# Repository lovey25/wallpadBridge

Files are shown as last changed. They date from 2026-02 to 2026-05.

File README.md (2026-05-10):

# 아파트 월패드 RS485-MQTT 브릿지 모듈

## 1. 프로젝트 개요

아파트 내부 RS485 네트워크(월패드-각 가전기기 간 통신)에 접속하여 데이터를 모니터링하고 제어 명령을 전달하는 하이브리드 IoT 게이트웨이 구축.

## 2. 시스템 아키텍처

지원 보드: **Wemos D1 Mini (ESP8266)**, **ESP-12E (ESP8266)**, **ESP32**

Physical Layer: 월패드 RS485 라인 (9600bps, 12V 전원부 활용)
Transport Layer: WiFi (802.11 b/g/n)
Application Layer: MQTT (v3.1.1), WebSocket (실시간 로그), HTTP (설정 및 제어)

## 3. 기능 상세 정의 (Functional Requirements)

### 3.1 네트워크 및 설정 관리

- **WiFi 자동 프로비저닝**: 저장된 WiFi 정보가 없거나 접속 실패 시 자동으로 AP 모드(Wallpad_Setup) 진입
- **웹 기반 설정 UI**:
  - `/wifi.htm`: WiFi 네트워크 스캔 및 연결 설정
  - `/config.htm`: WiFi + MQTT 통합 설정 관리
  - 실시간 WiFi 스캔 (WebSocket 기반, 비동기)
  - 설정 저장 후 자동 재부팅
- **REST API**:
  - `GET/POST /api/config`: WiFi/MQTT 설정 조회 및 업데이트
  - `GET /api/devices`: 모든 장치 상태 조회
- **영구 저장**: LittleFS 파일시스템 (256KB, config.json)

### 3.2 RS485 통신 및 디버깅 (보드별 시리얼 방식)

- **양방향 프로토콜 브릿지**:
  - RS485 → MQTT: 수신 패킷을 파싱하여 MQTT Topic으로 발행
  - MQTT → RS485: MQTT 명령을 RS485 프레임으로 변환 송신
  - 지원 장치: 조명(Light), 환기팬(Fan), 도어락(DoorLock), 온도조절기(Climate)
- **TX 큐 시스템**:
  - 6슬롯 원형 큐로 RS485 송신 직렬화 (WS / MQTT / HTTP / Poll 소스 구분)
  - 버스 Idle 대기(20ms) + TX 최소 간격(50ms) + 강제 송신 타임아웃(500ms)
  - 큐 오버플로 시 MQTT 경고, TX 통계 60초마다 `home/wallpad/diag/tx` 발행
- **3분 주기 상태 폴링**: 조명 3 + 온도조절기 4 = 7패킷 순차 발행 (PROGMEM 저장)
- **실시간 모니터링**:
  - `/monitor.htm`: WebSocket 기반 실시간 시리얼 로그 뷰어
  - `/ws`: 양방향 WebSocket 엔드포인트 (RS485 ↔ Web)
  - HEX 포맷 패킷 표시 및 장치 타입/명령 디코딩
  - `/api/rs485/send`: HEX 문자열 직접 송신 (F7…EE 프레임 검증 후 큐 추가)
  - `/api/rs485/diag`: TX 큐 통계 실시간 조회
- **Binary 센서**: 3채널 접점 신호 감지 (Pull-up, 12V 입력)
  - D1 Mini / ESP-12E: D5 / D6 / D7 (GPIO14 / GPIO12 / GPIO13)
  - ESP32: GPIO25 / GPIO26 / GPIO27

### 3.3 Home Assistant 연동

- **MQTT Discovery**: 재부팅 시 자동으로 장치 등록 메시지 발행
  - Light 엔티티 3개 (거실1 거실2, 3way)
  - Fan 엔티티 (속도 제어 1-3단)
  - Door Lock 엔티티 (도어락 제어 응답 기반, SubCommand `0x43`)
  - Climate 엔티티 4개 (온도조절기 4개(거실, 안방, 작은방1, 작은방2), 모드/온도 제어)
  - Binary Sensor 엔티티: 외부 접점 3개 + RS485 현관문 1개 (`device_class: door`, broadcast SubCommand `0x40`)
  - Device 정보(`bridge_info.h`): 식별자/이름/모델/제조사/버전 단일 헤더로 분리 — `credentials.h` 또는 PlatformIO `build_flags`로 override 가능
- **가용성 관리**: LWT(Last Will and Testament)를 통한 온라인/오프라인 상태 실시간 모니터링
- **상태 동기화**: RS485 장치 상태 변경 시 즉시 MQTT 발행 (변경 감지 기반)

### 3.4 시스템 안정성

- **Watchdog 타이머**: WiFi/MQTT 연결 상태 감시 (30초 주기)
- **RS485 활동 Watchdog**: 부팅 5분 후 활성화, 10분 무수신 시 MQTT 경고 후 자동 재부팅
- **연속 invalid frame 감지**: 100회 연속 or 512바이트 내 정상 프레임 없으면 파서 강제 리셋
- **메모리 모니터링**: 10초마다 힙 메모리 체크, 10KB 이하 시 경고
- **자동 재연결**: WiFi 연결 끊김 시 자동 재시도 (3회 실패 시 재부팅)
- **안전한 재부팅**: HTTP 응답 완료 후 지연 재부팅 (Exception 방지)
- **WDT 리셋 방지**: 비동기 WiFi 스캔, Ticker ISR 안전성 확보

### 3.5 OTA 펌웨어 업데이트

- **ArduinoOTA 지원**: WiFi STA 연결 시 OTA 서비스 자동 활성화
- **호스트명 설정**: `OTA_HOSTNAME` 매크로로 네트워크 식별 이름 지정
- **비밀번호 보호**: `OTA_PASSWORD` 매크로로 OTA 인증 설정 가능
- **업데이트 상태 반영**: OTA 진행 중 MQTT 상태를 `updating`으로 발행

### 3.6 성능 최적화

- **WiFi 스캔 최적화**:
  - Hidden SSID 스캔 제외로 스캔 시간 10배 단축
  - 비동기 스캔으로 UI blocking 제거
  - scanDelete()로 메모리 효율성 개선
- **WebSocket 즉시 연결**:
  - monitor.htm의 script를 body 끝으로 이동하여 HTML 파싱 blocking 제거
  - CSS 외부 파일화로 페이지 크기 26% 감소
  - 페이지 전환 시 WebSocket 정리 로직 개선 (다중 이벤트 리스너)
  - 연결 시간: 8초 → 20ms (400배 개선)
- **백엔드 비동기 처리**:
  - MQTT 연결을 부팅 20초 후로 지연 (웹 서버 우선 응답)
  - Discovery를 200ms 간격으로 분산 발행 (blocking 최소화)
  - MQTT 버퍼 크기 1024바이트로 확대 (Climate discovery 메시지 지원)
- **파일 시스템 접근 최적화**:
  - 정적 파일 서빙 시 fileSystemBusy 체크 제거 (읽기 전용은 안전)
  - 동시 요청 처리 개선

### 3.7 RS485 통신 규격

프로토콜 상세 명세는 [wallpad_protocol.md](./wallpad_protocol.md) 참조

## 4. 하드웨어 설계 (Hardware Specifications)

### 4.1 주요 부품 리스트

- MCU: **Wemos D1 Mini** 또는 **ESP-12E** (ESP8266) 또는 **ESP32** 개발 보드 중 선택
- Interface: XY-017 RS485-TTL 컨버터 (자동 방향 제어 기능 포함)
- Power: 12V to 5V DC-DC Stepdown (AMS1117-5V 사용 시 방열 주의, 고효율을 위해 Buck Converter 권장)
- Input Protection: 바이너리 센싱용 포토커플러 회로 (12V 입력 대응)

### 4.2 핀 맵 (Pin Mapping)

#### Wemos D1 Mini (SoftwareSerial — `USE_SOFTWARE_SERIAL`)

| 기능 | 핀 | GPIO | 비고 |
| :--- | :--- | :----- | :--- |
| **RS485 RX** | D2 | GPIO4  | SoftwareSerial RX (12V 레벨 변환 필수) |
| **RS485 TX** | D1 | GPIO5  | SoftwareSerial TX |
| **Binary In 1** | D5 | GPIO14 | 12V 신호 입력 (포토커플러 경유) |
| **Binary In 2** | D6 | GPIO12 | 12V 신호 입력 (포토커플러 경유) |
| **Binary In 3** | D7 | GPIO13 | 12V 신호 입력 (포토커플러 경유) |
| **Power In** | 5V / GND | - | AMS1117-5V 출력 연결 |

#### ESP-12E (HardwareSerial UART0 swap — `USE_HW_SERIAL_SWAP`)

> UART0 핀이 GPIO1(TX)/GPIO3(RX)에서 **GPIO15(TX)/GPIO13(RX)** 으로 스왑됩니다.
> 초기 플래싱은 기본 UART0 핀(GPIO1/GPIO3)으로 진행하고, 이후 OTA를 활용하세요.

| 기능 | GPIO | 비고 |
| :--- | :--- | :--- |
| **RS485 RX** | GPIO13 | UART0 swap RX (12V 레벨 변환 필수) |
| **RS485 TX** | GPIO15 | UART0 swap TX |
| **Binary In 1** | GPIO14 | 12V 신호 입력 (포토커플러 경유) |
| **Binary In 2** | GPIO12 | 12V 신호 입력 (포토커플러 경유) |
| **Binary In 3** | GPIO13 | ⚠ RS485 RX와 충돌 — 재배치 필요 |
| **Power In** | 3V3 / GND | - |

> ⚠ ESP-12E에서 GPIO13이 RS485 RX와 Binary In 1을 공유합니다.  
> Binary 센서 3채널 모두 사용할 경우 별도 핀(예: GPIO4, GPIO5, GPIO14)으로 재배치하고  
> `main.cpp` 상단 `BINARY_PIN_*` 정의를 수정하세요.

#### ESP32 (`esp32dev` — HardwareSerial2)

| 기능 | GPIO | 비고 |
| :--- | :--- | :--- |
| **RS485 RX** | GPIO16 | Serial2 RX (3.3V 로직, 레벨 변환 필수) |
| **RS485 TX** | GPIO17 | Serial2 TX |
| **Binary In 1** | GPIO25 | 12V 신호 입력 (포토커플러 경유) |
| **Binary In 2** | GPIO26 | 12V 신호 입력 (포토커플러 경유) |
| **Binary In 3** | GPIO27 | 12V 신호 입력 (포토커플러 경유) |
| **Power In** | 5V / GND | - |

## 5. 소프트웨어 스택 (Library Stack)

PlatformIO 환경에서 다음 라이브러리를 조합하여 구현합니다.

Framework: Arduino

Async WebServer:

- ESP8266: ESPAsyncWebServer + ESPAsyncTCP
- ESP32: ESPAsyncWebServer + AsyncTCP

MQTT Client: PubSubClient

JSON Parser: ArduinoJson

File System: LittleFS (SPIFFS 대비 안정성 및 속도 우위)

## 6. 빌드 및 플래시 방법

### 6.1 환경(env) 목록

| env 이름  | 보드 | 시리얼 방식 | OTA 대응 |
| :--- | :--- | :--- | :--- |
| `d1_mini` | Wemos D1 Mini | SoftwareSerial  | `d1_mini_ota` |
| `esp12e`  | ESP-12E | UART0 swap | `esp12e_ota`  |
| `esp32` | ESP32 Dev | HardwareSerial2 | `esp32_ota` |

### 6.2 펌웨어 빌드

```bash
# D1 Mini
pio run -e d1_mini

# ESP-12E
pio run -e esp12e

# ESP32
pio run -e esp32
```

### 6.3 펌웨어 유선 업로드

```bash
# D1 Mini
pio run -e d1_mini -t upload

# ESP-12E
pio run -e esp12e -t upload

# ESP32
pio run -e esp32 -t upload
```

### 6.4 파일시스템(LittleFS) 업로드

```bash
# D1 Mini
pio run -e d1_mini -t buildfs && pio run -e d1_mini -t uploadfs

# ESP-12E
pio run -e esp12e -t buildfs && pio run -e esp12e -t uploadfs

# ESP32
pio run -e esp32 -t buildfs && pio run -e esp32 -t uploadfs
```

### 4.3 회로 (D1 Mini 기준)

```.
[ 12V DC POWER ]                [ DC-DC BUCK CONVERTER ]
 월패드 12V (+) ----------------------- [IN+]         [OUT+] ---+--- 5V (System VCC)
 월패드 GND (-) ----------------------- [IN-]         [OUT-] ---|--- GND (System GND)
                                                                |
      +---------------------------------------------------------+
      |
      |      [ WEMOS D1 MINI ]                [ XY-017 RS485 MODULE ]
      +------- 5V (VIN)                          VCC ----------- 5V
      |        GND ------------------------------ GND ----------- GND
      |                                           TXD ----------- D1 (GPIO5)
      |                                           RXD ----------- D2 (GPIO4)
      |                                            A  ----------- 월패드 RS485 (A)
      |                                            B  ----------- 월패드 RS485 (B)
      |
      |      [ BINARY SENSING (3 Channels) ]
      |      * PC817 Optocoupler (Typical for 1 ch)
      |
월패드 12V(S1) --[ 1kΩ Resistor ]-- (Pin 1:Anode)  (Pin 4:Collector) --- D5 (GPIO14)
월패드 GND ------------------------ (Pin 2:Cathode)(Pin 3:Emitter)   --- GND
      |
월패드 12V(S2) --[ 1kΩ Resistor ]-- (Pin 1:Anode)  (Pin 4:Collector) --- D6 (GPIO12)
월패드 GND ------------------------ (Pin 2:Cathode)(Pin 3:Emitter)   --- GND
      |
월패드 12V(S3) --[ 1kΩ Resistor ]-- (Pin 1:Anode)  (Pin 4:Collector) --- D7 (GPIO13)
월패드 GND ------------------------ (Pin 2:Cathode)(Pin 3:Emitter)   --- GND

--------------------------------------------------------------------------------
[설계 참고사항]
1. Wemos D1 Mini의 D5, D6, D7은 소프트웨어에서 INPUT_PULLUP으로 설정.
2. RS485 모듈(XY-017)은 5V 전원을 사용하되, 데이터 핀(TXD/RXD)은 Wemos의 3.3V 로직과 직결 (9600bps 가동 시 안정적).
```

<table>
  <tr>
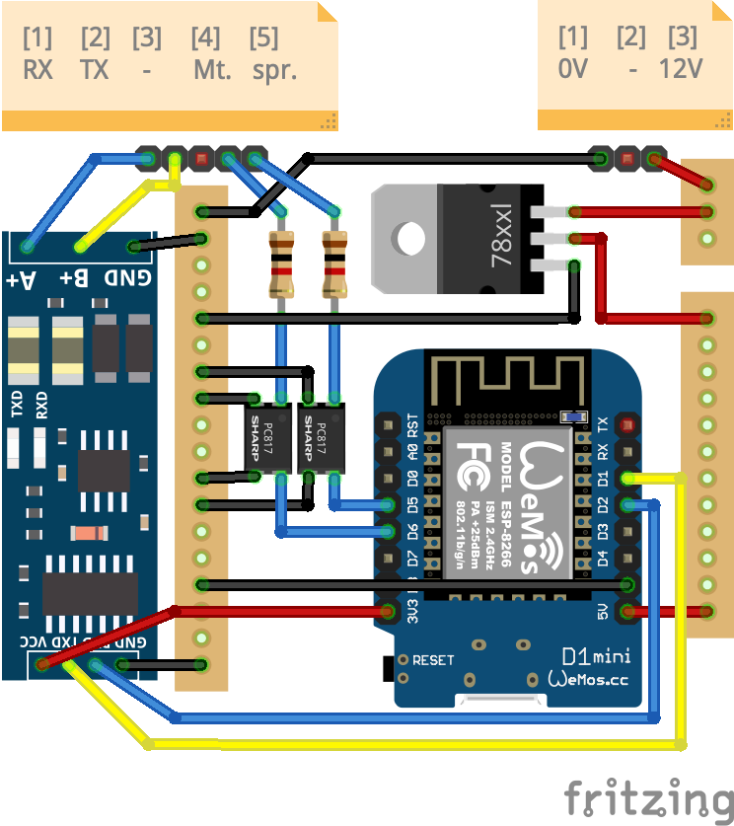
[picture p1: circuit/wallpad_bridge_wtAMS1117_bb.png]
HW
    <td></td>
  </tr>
</table>

### 6. 인터페이스 명세 (Endpoints)

| Endpoint | Method | Description |
| :--- | :----- | :--- |
| `/` | GET | 시스템 상태 대시보드 및 메인 홈 페이지 |
| `/monitor.htm` | GET | 실시간 시리얼 로그 뷰어 (WebSocket 연동) |
| `/wifi.htm` | GET | `/config.htm`으로 리다이렉트 |
| `/config.htm` | GET | 시스템 설정 관리 (WiFi + MQTT 통합 설정) |
| `/ws` | WS | Serial <-> Web 인터페이스 실시간 데이터 스트림 |
| `/scan` | GET | 주변 WiFi AP 리스트 스캔 및 JSON 반환 (비동기) |
| `/wifistatus` | GET | 현재 연결 상태 및 네트워크 정보 |
| `/wifireset` | POST | 저장된 WiFi 설정 삭제 및 모듈 재부팅 |
| `/connect2ssid` | POST | SSID 및 비밀번호 수신/저장 |
| `/reboot` | POST | 설정 유지 재부팅 |
| `/api/config` | GET | 현재 설정 조회 (WiFi + MQTT, JSON 응답) |
| `/api/config` | POST | 설정 업데이트 (WiFi + MQTT, JSON body) |
| `/api/devices` | GET | 모든 장치 상태 조회 (JSON) |
| `/api/rs485/send` | POST | RS485 HEX 프레임 직접 송신 (F7…EE 검증 후 큐 추가) |
| `/api/rs485/diag` | GET | RS485 TX 큐 통계 및 진단 정보 조회 (JSON) |
| `/api/monitor/ping`  | POST | 모니터 세션 활성 유지 ping |
| `/api/monitor/leave` | POST | 모니터 세션 이탈 알림 |
| `/savepreset` | POST | RS485 제어 프리셋 데이터 저장 |
| `/preset.ini` | GET | 저장된 프리셋 파일 다운로드/조회 |

## 7. 구현 상태 (Implementation Status)

### ✅ 완료된 기능

- **RS485 프로토콜 엔진**: 파싱, 디코딩, 상태 관리, 명령 생성 (Light, Fan, DoorLock, Climate)
- **RS485 TX 큐**: 6슬롯 원형 큐, 버스 Idle 대기, 소스 추적 (WS/MQTT/HTTP/Poll)
- **RS485 진단**: TX 통계 자동 발행(`home/wallpad/diag/tx`), `/api/rs485/diag` API
- **RS485 안정성**: 활동 Watchdog(10분 무수신→재부팅), 연속 invalid frame 자동 복구
- **상태 폴링**: 조명 3 + 온도조절기 4채널 3분 주기 자동 조회
- **WiFi 네트워크**: Station/AP 모드, 비동기 스캔, 자동 프로비저닝
- **웹 UI**: 대시보드, 설정 관리, 실시간 모니터 (4개 페이지, 다크 테마)
- **MQTT 통합**: 양방향 통신, Home Assistant Discovery, LWT
- **REST API**: 설정 조회/업데이트, 장치 상태 조회, RS485 직접 송신·진단
- **WebSocket**: 실시간 RS485 로그, WiFi 스캔 알림, 30초 ping
- **시스템 안정성**: WiFi/MQTT Watchdog, 메모리 모니터링, 자동 재연결
- **OTA 업데이트**: ArduinoOTA 기반 무선 펌웨어 업로드 (진행 상태 MQTT 발행 포함)

### 🚀 향후 계획

자세한 개발 로드맵은 [TODO.md](./TODO.md) 참조:

- 실제 월패드 하드웨어 RS485 통신 테스트

## 8. OTA 사용 방법

### 8.1 OTA 설정

`src/credentials.h`에 아래 항목을 추가하거나 수정합니다.

```cpp
#define OTA_HOSTNAME "wallpad-bridge"
#define OTA_PASSWORD ""
```

- `OTA_PASSWORD`를 빈 문자열로 두면 인증 없이 OTA 업로드가 허용됩니다.
- 운영 환경에서는 반드시 강한 비밀번호를 설정하세요.

### 8.2 OTA 펌웨어 업로드

장치가 WiFi에 연결된 상태에서 아래 명령으로 OTA 업로드합니다.  
`upload_port`는 `platformio.ini`의 `[env:*_ota]` 섹션에서 설정합니다.

```bash
# D1 Mini
pio run -e d1_mini_ota -t upload

# ESP-12E
pio run -e esp12e_ota -t upload

# ESP32
pio run -e esp32_ota -t upload
```

### 8.3 LittleFS OTA 업로드

```bash
# D1 Mini
pio run -e d1_mini_ota -t uploadfs

# ESP-12E
pio run -e esp12e_ota -t uploadfs

# ESP32
pio run -e esp32_ota -t uploadfs
```

직접 IP를 지정할 경우:

```bash
pio run -e <env>_ota -t uploadfs --upload-port <장치_IP>
```

## 9. 참고 문서 (References)

- [TODO.md](./TODO.md) - 상세 로드맵 및 작업 목록
- [wallpad_protocol.md](./wallpad_protocol.md) - RS485 통신 규약
- [PlatformIO Documentation](https://docs.platformio.org/)
- [Home Assistant MQTT Discovery](https://www.home-assistant.io/docs/mqtt/discovery/)

---

## 10. 라이선스 (License)

MIT License - 자유롭게 사용, 수정, 배포 가능합니다.

---

## 📝 알려진 제한사항

| 항목 | D1 Mini / ESP-12E (ESP8266) | ESP32 |
| :--- | :--- | :--- |
| **메모리** | 힙 ~45KB — 동시 처리 장치 수 제한 | 힙 ~270KB — 여유 있음 |
| **RS485** | SoftwareSerial(D1 Mini) 9600bps 제한 / ESP-12E는 HardwareSerial | HardwareSerial2, 고속 baud 지원 가능 |
| **WebSocket** | 동시 연결 최대 8개 (메모리 제약) | 동시 연결 여유 있음 |
| **LittleFS** | 1MB 파티션 (4M flash 기준) | 파티션 테이블 설정에 따라 가변 |
| **ESP-12E Binary In** | GPIO13이 RS485 RX 겸용 — 3채널 모두 필요 시 핀 재배치 필요 | 해당 없음 |

## ✅ 최근 해결된 이슈

### 2026-05-10: 현관문 broadcast 채널 + 디바이스 메타정보 분리

- **현관문 sub-protocol 분리**: 도어락(`0x1E`) 디바이스의 SubCommand 채널을 `0x40`(상태 broadcast) / `0x43`(제어 응답)으로 명시 분리
- **RS485Frame 확장**: 파서에 `subCommand`(buffer[5]) 필드 추가 — 동일 deviceType 내 sub-protocol 구분 가능
- **HA 신규 엔티티**: 현관문 `binary_sensor`(`device_class: door`) 자동 등록, 토픽 `home/wallpad/frontdoor/state`
- **bridge_info.h**: HA Discovery용 디바이스 메타정보(식별자/이름/모델/제조사/버전)를 단일 헤더 매크로로 분리, 두 군데 중복 제거 + `#ifndef` 가드로 build flag override 지원

### 2026-04-28: ESP12e / ESP32 멀티보드 지원 추가

- **플랫폼 분기**: `#ifdef ESP32` / `USE_SOFTWARE_SERIAL` / `USE_HW_SERIAL_SWAP` 빌드 플래그로 단일 코드베이스에서 3개 보드 지원
- **ESP12e**: UART0 swap(GPIO13=RX, GPIO15=TX) HardwareSerial 적용 — SoftwareSerial 타이밍 오류 없음
- **ESP32**: Serial2(GPIO16=RX, GPIO17=TX) + Binary 센서 GPIO25/26/27 적용
- **platformio.ini**: `[common_esp8266]` 공통 섹션 추출, `[env:esp32]` / `[env:esp32_ota]` 신설
- **메모리 임계값**: ESP32 `WS_MEMORY_GUARD_THRESHOLD` 50000으로 상향

### 2026-03-22: RS485 제어/모니터링 정합성 개선

- **체크섬 계산 수정**: `crc=0xF7` 초기화 XOR 방식으로 통일
- **프레임 파서 수정**: 주소/데이터 오프셋을 프로토콜 포맷에 맞게 보정
- **조명 상태 토픽 수정**: `home/wallpad/light/1..3/state`로 정합성 확보
- **monitor.htm 테스트 명령 수정**: 잘못된 HEX 샘플 교정 및 입력 검증(짝수 길이) 추가
- **루프백 테스트 가이드 추가**: 단일보드 SoftwareSerial 자기 루프백은 참고용으로만 사용

### 2026-02-18: 성능 최적화

- **WebSocket 연결 지연 (8초)**: monitor.htm의 script를 head → body 끝으로 이동하여 해결
- **WiFi 스캔 느림 (10초+)**: Hidden SSID 스캔 제외로 해결
- **MQTT Discovery blocking**: 비동기 분산 발행으로 개선
- **Climate 엔티티 표시 오류**: Discovery 설정 수정 및 mode 소문자 변경

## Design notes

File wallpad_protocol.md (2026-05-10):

# RS485 통신 규약 명세서

## 1. 물리/링크 계층 설정

| 항목 | 값 |
| --- | --- |
| Baud Rate | 9600 |
| Data Bits | 8 |
| Parity | None |
| Stop Bits | 1 |
| RX Frame Timeout | 10 ms |
| TX Interval | 50 ms |
| ACK Timeout | 50 ms |
| ACK Retry | 1 |
| Prefix | `F7` |
| Suffix | `EE` |
| Checksum | XOR (Checksum8) |

### Checksum 알고리즘

```cpp
crc = 0xF7
for byte in payload:
    crc ^= byte
return crc
```

---

## 2. 공통 프레임 구조

```.
[Prefix] [Length] [Device] [Command] [Data...] [Checksum] [Suffix]
```

| 필드 | 설명 |
| --- | --- |
| Prefix | 프레임 시작 (`F7`) |
| Length | Prefix 제외 데이터 길이 |
| Device | 장치 타입 + 주소 |
| Command  | 동작 코드 |
| Data | 상태값 또는 설정값 |
| Checksum | XOR 결과 |
| Suffix | 프레임 종료 (`EE`) |

> **표기 규칙**
>
> - 본 문서의 장치별 예시는 이해를 위해 주로 `Prefix~Data`까지만 표기합니다.
> - 실제 송수신 프레임은 항상 마지막에 `Checksum`과 `Suffix(EE)`를 포함해야 합니다.

---

## 3. 주소 체계

| 구분 | 값 |
| --- | ---- |
| 거실조명1 | `11` |
| 거실조명2 | `12` |
| 3Way 조명 | `13` |
| 환기 | `11` |
| 거실 난방 | `11` |
| 방1 난방  | `12` |
| 방2 난방  | `13` |
| 방3 난방  | `14` |

---

## 4. 장치별 프로토콜

### 4.1 조명 (Binary Light)

#### 상태 조회

```.
REQ: F7 0B 01 19 01 40 AA 00 00
RES: F7 0B 01 19 04 40 AA 00 SS
```

| 값 | 의미 |
| --- | --- |
| `AA` | 조명 주소 |
| `SS=01` | ON |
| `SS=02` | OFF |

#### 제어

```.
ON  REQ: F7 0B 01 19 02 40 AA 01 00
ON  RES: F7 0B 01 19 04 40 AA 01 01

OFF REQ: F7 0B 01 19 02 40 AA 02 00
OFF RES: F7 0B 01 19 04 40 AA 02 02
```

- 조명 제어 프레임의 마지막 `00`은 예약(패딩) 바이트로, 명령 길이(`0B`)에 포함됩니다.

---

### 4.2 환기장치 (Fan)

#### 상태 조회

```.
REQ: F7 0B 01 2B 01 40 11 00 00
RES: F7 0C 01 2B 04 40 11 00 PS
```

| 필드 | 값 | 의미 |
| ---- | ---- | ---- |
| 전원 | `02` | OFF  |
| 전원 | `01` | ON |
| 풍량 | `01` | 약 |
| 풍량 | `03` | 중 |
| 풍량 | `07` | 강 |

#### 전원 제어

```.
OFF REQ: F7 0B 01 2B 02 40 11 02 00
ON  REQ: F7 0B 01 2B 02 42 11 01 00
```

#### 풍량 제어

```.
LOW  : F7 0B 01 2B 02 42 11 01 00
MED  : F7 0B 01 2B 02 42 11 03 00
HIGH : F7 0B 01 2B 02 42 11 07 00
```

---

### 4.3 도어락

도어락(Device `1E`)은 SubCommand 바이트(`Data[0]`, 인덱스 5)에 따라
**제어 응답(`43`)** 과 **현관문 상태 broadcast(`40`)** 가 분리되어 있다.

#### 도어락 열림 제어

```.
REQ: F7 0E 01 1E 02 43 11 04 00 04 FF FF
RES: F7 0C 01 1E 04 43 11 04 00 04
```

- SubCommand `43` : 도어락 제어/응답 채널.
- 응답 데이터 첫 바이트 `04` 가 "열림 명령 수락" 의미.

#### 현관문 상태 (door sensor broadcast)

월패드는 현관문 자체의 열림/닫힘 상태를 주기적으로 broadcast 한다.

```.
RES (닫힘): F7 0C 01 1E 04 40 11 00 02 03
RES (열림): F7 0C 01 1E 04 40 11 00 02 04
```

| 필드 | 값 | 의미 |
| --- | --- | --- |
| SubCommand | `40` | 상태 broadcast 채널 |
| Address | `11` | 현관문 주소 |
| Data[0..1] | `00 02` | 고정 |
| Data[2] (ST)  | `03` | 닫힘 (CLOSED) |
| Data[2] (ST)  | `04` | 열림 (OPEN) |

> 본 채널은 요청 없이 월패드가 자발적으로 송출하므로 별도의 폴링은 불필요하다.

---

### 4.4 난방 (Climate)

#### 상태 조회

```.
REQ: F7 0B 01 18 01 45 RR 00 00
RES: F7 0D 01 18 04 45 RR 00 SS CC TT
```

| 필드 | 의미 |
| --- | --- |
| `RR` | 룸 주소 |
| `SS=01` | 난방 |
| `SS=04` | OFF |
| `SS=07` | 외출 |
| `CC` | 현재 온도 |
| `TT` | 설정 온도 |

#### 전원/모드 제어

```.
HEAT REQ: F7 0B 01 18 02 46 RR 01 00
OFF  REQ: F7 0B 01 18 02 46 RR 04 00
AWAY REQ: F7 0B 01 18 02 46 RR 07 00
```

#### 온도 설정

```.
REQ: F7 0B 01 18 02 45 RR TT 00
RES: F7 0D 01 18 04 45 RR TT 01 CC TT
```

---

## 5. 상태 코드 요약

| 구분 | 값 | 의미 |
| --- | --- | --- |
| Power ON | `01` | 동작 |
| Power OFF  | `02` 또는 `04` | 장치별 상이 |
| Away | `07` | 외출 모드 |
| Fan Low | `01` | 약 |
| Fan Medium | `03` | 중 |
| Fan High | `07` | 강 |

---

## 6. 설계 특징

- 모든 프레임은 **Prefix(F7) / Suffix(EE)** 구조 사용
- **XOR Checksum** 기반 단순 무결성 검증
- **요청 → ACK 응답 구조**
- 장치 타입별 **Command 코드 분리**
- 온도/풍량 등은 **단일 바이트 파라미터 방식**

---

## 7. 현장 검증용 기본 조회 프레임 (2026-03-22)

아래 프레임은 모니터 페이지 빠른 테스트 명령과 동일한 값입니다.

- 조명1 조회: `F70B01190140110000B4EE`
- 환기 조회: `F70B012B014011000086EE`
- 거실 난방 조회: `F70B01180145110000B0EE`

> 참고: 단일 Wemos D1 mini에서 D1(TX)-D2(RX) 직접 연결만으로 수행하는
> SoftwareSerial 자기 루프백 테스트는 하드웨어/타이밍 제약으로 신뢰도가 낮습니다.
> 실사용 검증은 RS485 트랜시버 2개 이상 또는 외부 UART 리시버를 권장합니다.

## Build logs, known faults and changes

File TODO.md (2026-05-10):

# 개발 로드맵 (Development Roadmap)

> 완료된 기능 목록은 [README.md](./README.md) 7절 참조

---

## 🎯 미완료 항목 (Pending)

### RS485 통신 테스트

- [ ] 신규 프레임 발견 시 `wallpad_protocol.md` 보완 (실수신 데이터 기반)

### Home Assistant 통합 검증

- [ ] LWT(Last Will Testament) 동작 확인 (하드웨어 연결 후 실환경 검증 필요)
- [ ] 상태 동기화 검증 (RS485 → MQTT, 하드웨어 연결 후 실환경 검증 필요)

---

## 🚀 향후 개발 과제

### Phase 1: 보안 및 안정성

**Priority: Medium**

- [ ] **웹 UI 인증**
  - HTTP Basic Auth 구현
  - 관리자 비밀번호 설정 UI
  - 세션 타임아웃
- [ ] **MQTT over TLS**
  - 인증서 관리
  - 보안 연결 옵션
- [ ] **설정 백업/복구**
  - config.json 내보내기 (`/api/config` GET 이미 일부 구현됨)
  - 공장 초기화 API (`/factory-reset`)

### Phase 2: OTA 안정성

**Priority: Medium**

- [ ] OTA 업데이트 실패 시 롤백 메커니즘

---

## 🔧 개선 아이디어

- ESP32로 포팅 (더 많은 메모리, 하드웨어 UART)
- Captive Portal 개선 (WiFi 설정 시 자동 팝업)
- 다국어 지원 (영어, 한국어)
- 다크/라이트 테마 전환
- 모바일 반응형 UI 개선
- Fan 속도 변경 MQTT 토픽 전용화 (`home/wallpad/fan/speed/set`)

---

## 📚 참고 문서

- [README.md](./README.md) - 프로젝트 개요 및 기능 설명
- [wallpad_protocol.md](./wallpad_protocol.md) - RS485 통신 프로토콜
- [PlatformIO Documentation](https://docs.platformio.org/)
- [Home Assistant MQTT Discovery](https://www.home-assistant.io/docs/mqtt/discovery/)
- [ESPAsyncWebServer](https://github.com/me-no-dev/ESPAsyncWebServer)

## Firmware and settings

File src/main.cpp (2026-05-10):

#include "credentials.h"
#include <Arduino.h>
#ifdef ESP32
#include <WiFi.h>
#include <esp_wifi.h>
#else
#include <ESP8266WiFi.h>
#ifdef USE_SOFTWARE_SERIAL
#include <SoftwareSerial.h>
#endif
#endif
#include <ArduinoOTA.h>
#include <ESPAsyncWebServer.h>
#include <PubSubClient.h>
#include <ArduinoJson.h>
#include <LittleFS.h>
#include <Ticker.h>
#include "checksum.h"
#include "rs485_parser.h"
#include "device_decoder.h"
#include "device_manager.h"
#include "command_builder.h"
#include "bridge_info.h"

// ─── RS485 시리얼 객체 ────────────────────────────────────────
// D1 Mini  : SoftwareSerial (D2=RX, D1=TX)
// ESP12e   : HardwareSerial UART0 swap (GPIO13=RX, GPIO15=TX)
// ESP32    : HardwareSerial UART2 (GPIO16=RX, GPIO17=TX)
#if defined(USE_SOFTWARE_SERIAL)
SoftwareSerial rs485(D2, D1);
#elif defined(ESP32)
HardwareSerial rs485(2);
#else
// USE_HW_SERIAL_SWAP: UART0 핀을 GPIO13(RX)/GPIO15(TX)로 스왑
HardwareSerial &rs485 = Serial;
#endif

const uint8_t MAX_WS_CLIENTS = 8;
#ifdef ESP32
const uint32_t WS_MEMORY_GUARD_THRESHOLD = 50000;
#else
const uint32_t WS_MEMORY_GUARD_THRESHOLD = 15000;
#endif
AsyncWebServer server(80);
AsyncWebSocket ws("/ws");
WiFiClient espClient;
PubSubClient mqtt(espClient);
Ticker watchdogTicker;

const char *configPath = "/config.json";
String wifi_ssid = WIFI_SSID;     // WiFi SSID
String wifi_pass = WIFI_PASS;     // WiFi Password
String mqtt_server = MQTT_SERVER; // MQTT 서버 (credentials.h에서 로드)
String mqtt_user = MQTT_USER;     // MQTT 사용자 (credentials.h에서 로드)
String mqtt_pass = MQTT_PASS;     // MQTT 비밀번호 (credentials.h에서 로드)
int mqtt_port = MQTT_PORT;        // MQTT 포트 (credentials.h에서 로드)

// RS485 프로토콜 엔진
RS485Parser parser;
DeviceManager deviceManager;

// Binary 센서 핀
#ifdef ESP32
const int BINARY_PIN_1 = 25;
const int BINARY_PIN_2 = 26;
const int BINARY_PIN_3 = 27;
#else
const int BINARY_PIN_1 = D5;
const int BINARY_PIN_2 = D6;
const int BINARY_PIN_3 = D7;
#endif
bool binarySensor1 = false;
bool binarySensor2 = false;
bool binarySensor3 = false;

// WiFi 스캔 결과 캐시
String cachedScanResults = "[]";
bool scanInProgress = false;
// 모니터 페이지 활성 상태 추적 (웹소켓 연결 우선 제어)
const bool ENABLE_MONITOR_PRIORITY = false;
bool monitorSessionActive = false;
unsigned long lastMonitorActivityMs = 0;
const unsigned long MONITOR_ACTIVE_TTL_MS = 15000;
// 파일 시스템 접근 보호
bool fileSystemBusy = false;
unsigned long lastFileAccess = 0;
const unsigned long FILE_ACCESS_DELAY = 50; // 50ms 최소 간격
// 메모리 모니터링
unsigned long lastMemoryCheck = 0;
const unsigned long MEMORY_CHECK_INTERVAL = 10000; // 10초
const uint32_t MEMORY_WARNING_THRESHOLD = 10000;   // 10KB 이하 시 경고 (상향)

// RS485 송신 최소 간격 제어 (프로토콜 문서: TX Interval 50ms)
unsigned long lastRS485TxTime = 0;
const unsigned long RS485_TX_MIN_INTERVAL_MS = 50;
const unsigned long RS485_BUS_IDLE_MS = 20;     // TX 전 버스 무활동 최소 대기 (ms)
const unsigned long RS485_TX_MAX_WAIT_MS = 500; // idle 대기 상한 (ms) - 초과 시 강제 송신

enum CommandSource
{
  COMMAND_SOURCE_WS,
  COMMAND_SOURCE_MQTT,
  COMMAND_SOURCE_HTTP,
  COMMAND_SOURCE_POLL
};

struct PendingRS485Command
{
  uint8_t buffer[32];
  uint8_t length;
  CommandSource source;
  unsigned long queuedTime;
};

struct RS485TxDiagnostics
{
  uint32_t enqueued = 0;
  uint32_t dequeued = 0;
  uint32_t dropped = 0;
  uint32_t forcedTx = 0;
  uint32_t blockedByBus = 0;
  uint8_t peakDepth = 0;
  unsigned long lastReportTime = 0;
};

const uint8_t RS485_COMMAND_QUEUE_SIZE = 6;
PendingRS485Command rs485CommandQueue[RS485_COMMAND_QUEUE_SIZE];
uint8_t rs485CommandQueueHead = 0;
uint8_t rs485CommandQueueTail = 0;
uint8_t rs485CommandQueueCount = 0;
RS485TxDiagnostics rs485TxDiagnostics;
bool rs485QueueDropReported = false;

// 상태 조회 폴링 패킷 (PROGMEM에 저장하여 RAM 절약)
static const uint8_t POLL_PACKETS[7][11] PROGMEM = {
    {0xF7, 0x0B, 0x01, 0x19, 0x01, 0x40, 0x11, 0x00, 0x00, 0xB4, 0xEE}, // light/1 state
    {0xF7, 0x0B, 0x01, 0x19, 0x01, 0x40, 0x12, 0x00, 0x00, 0xB7, 0xEE}, // light/2 state
    {0xF7, 0x0B, 0x01, 0x19, 0x01, 0x40, 0x13, 0x00, 0x00, 0xB6, 0xEE}, // light/3 state
    {0xF7, 0x0B, 0x01, 0x18, 0x01, 0x45, 0x11, 0x00, 0x00, 0xB0, 0xEE}, // climate/1 state
    {0xF7, 0x0B, 0x01, 0x18, 0x01, 0x45, 0x12, 0x00, 0x00, 0xB3, 0xEE}, // climate/2 state
    {0xF7, 0x0B, 0x01, 0x18, 0x01, 0x45, 0x13, 0x00, 0x00, 0xB2, 0xEE}, // climate/3 state
    {0xF7, 0x0B, 0x01, 0x18, 0x01, 0x45, 0x14, 0x00, 0x00, 0xB5, 0xEE}, // climate/4 state
};
const uint8_t NUM_POLL_PACKETS = 7;

const unsigned long STATUS_POLL_INTERVAL_MS = 180000UL;     // 3분
const unsigned long STATUS_POLL_PACKET_INTERVAL_MS = 200UL; // 패킷 간 200ms
unsigned long lastStatusPollTime = 0;
unsigned long lastStatusPollEnqueue = 0;
int8_t statusPollIndex = -1; // -1=비활성, 0~6=진행 중

// RS485 활동 감시 Watchdog
unsigned long lastRS485ActivityTime = 0;
bool rs485ActivityWatchdogEnabled = false;
const unsigned long RS485_WATCHDOG_ENABLE_DELAY_MS = 300000; // 부팅 5분 후 활성화
const unsigned long RS485_ACTIVITY_TIMEOUT_MS = 600000;      // 10분 무수신 시 재부팅

// 연속 invalid frame 카운터 (파서 상태 꼬임 감지)
int consecutiveInvalidFrames = 0;
uint32_t rs485BytesSinceLastFrame = 0;
const int MAX_CONSECUTIVE_INVALID = 100;
const uint32_t MAX_BYTES_WITHOUT_FRAME = 512;

// Watchdog 플래그 (콜백에서 Serial.print 방지)
bool shouldCheckWifiConnection = false;
bool shouldCheckMqttConnection = false;

// WiFi 모드 추적 (AP 모드인지 Station 모드인지)
bool isAPMode = false;

// WiFi 재연결 시도 카운터
int wifiReconnectAttempts = 0;
const int MAX_WIFI_RECONNECT_ATTEMPTS = 3; // 3회 실패 시 리부팅

// 재부팅 플래그 (HTTP 응답 완료 후 안전하게 재부팅)
bool shouldReboot = false;
unsigned long rebootScheduledTime = 0;

// OTA 상태
bool otaInProgress = false;

#ifndef OTA_HOSTNAME
#define OTA_HOSTNAME "wallpad-bridge"
#endif

#ifndef OTA_PASSWORD
#define OTA_PASSWORD ""
#endif

bool isMonitorSessionActive()
{
  if (!ENABLE_MONITOR_PRIORITY)
    return false;

  if (!monitorSessionActive)
    return false;

  // millis overflow-safe 비교
  unsigned long elapsed = millis() - lastMonitorActivityMs;
  if (elapsed > MONITOR_ACTIVE_TTL_MS)
  {
    monitorSessionActive = false;
    return false;
  }

  return true;
}

unsigned long elapsedSince(unsigned long startTime)
{
  return millis() - startTime;
}

const char *commandSourceToString(CommandSource source)
{
  switch (source)
  {
  case COMMAND_SOURCE_WS:
    return "ws";
  case COMMAND_SOURCE_MQTT:
    return "mqtt";
  case COMMAND_SOURCE_HTTP:
    return "http";
  case COMMAND_SOURCE_POLL:
    return "poll";
  default:
    return "unknown";
  }
}

uint8_t getRS485CommandQueueDepth()
{
  return rs485CommandQueueCount;
}

void publishRs485TxDiagnostics(bool forceReport = false)
{
  if (!mqtt.connected())
    return;

  if (!forceReport && elapsedSince(rs485TxDiagnostics.lastReportTime) < 60000)
    return;

  rs485TxDiagnostics.lastReportTime = millis();

  char payload[192];
  snprintf(payload, sizeof(payload),
           "{\"queued\":%lu,\"sent\":%lu,\"dropped\":%lu,\"forced\":%lu,\"blocked\":%lu,\"depth\":%u,\"peak\":%u}",
           static_cast<unsigned long>(rs485TxDiagnostics.enqueued),
           static_cast<unsigned long>(rs485TxDiagnostics.dequeued),
           static_cast<unsigned long>(rs485TxDiagnostics.dropped),
           static_cast<unsigned long>(rs485TxDiagnostics.forcedTx),
           static_cast<unsigned long>(rs485TxDiagnostics.blockedByBus),
           getRS485CommandQueueDepth(),
           rs485TxDiagnostics.peakDepth);
  mqtt.publish("home/wallpad/diag/tx", payload, true);
}

String getRs485TxDiagJson(const char *status = nullptr, const char *message = nullptr)
{
  String json = "{";
  if (status != nullptr)
  {
    json += "\"status\":\"";
    json += status;
    json += "\",";
  }
  if (message != nullptr)
  {
    json += "\"message\":\"";
    json += message;
    json += "\",";
  }

  json += "\"queued\":" + String(rs485TxDiagnostics.enqueued) + ",";
  json += "\"sent\":" + String(rs485TxDiagnostics.dequeued) + ",";
  json += "\"dropped\":" + String(rs485TxDiagnostics.dropped) + ",";
  json += "\"forced\":" + String(rs485TxDiagnostics.forcedTx) + ",";
  json += "\"blocked\":" + String(rs485TxDiagnostics.blockedByBus) + ",";
  json += "\"depth\":" + String(getRS485CommandQueueDepth()) + ",";
  json += "\"peak\":" + String(rs485TxDiagnostics.peakDepth) + ",";
  json += "\"free_heap\":" + String(ESP.getFreeHeap()) + ",";
  json += "\"rs485_idle_ms\":" + String(elapsedSince(lastRS485ActivityTime));
  json += "}";
  return json;
}

bool isHexChar(char c)
{
  return (c >= '0' && c <= '9') ||
         (c >= 'A' && c <= 'F') ||
         (c >= 'a' && c <= 'f');
}

uint8_t hexCharToValue(char c)
{
  if (c >= '0' && c <= '9')
    return static_cast<uint8_t>(c - '0');
  if (c >= 'A' && c <= 'F')
    return static_cast<uint8_t>(c - 'A' + 10);
  return static_cast<uint8_t>(c - 'a' + 10);
}

bool parseWallpadHexFrame(String hexInput, uint8_t *outBuffer, size_t maxLen, size_t &outLen)
{
  hexInput.replace(" ", "");
  hexInput.toUpperCase();

  if (hexInput.length() < 14 || hexInput.length() % 2 != 0)
    return false;

  if (!hexInput.startsWith("F7") || !hexInput.endsWith("EE"))
    return false;

  for (size_t i = 0; i < hexInput.length(); i++)
  {
    if (!isHexChar(hexInput[i]))
      return false;
  }

  outLen = hexInput.length() / 2;
  if (outLen == 0 || outLen > maxLen)
    return false;

  for (size_t i = 0; i < outLen; i++)
  {
    char high = hexInput[i * 2];
    char low = hexInput[i * 2 + 1];
    outBuffer[i] = static_cast<uint8_t>((hexCharToValue(high) << 4) | hexCharToValue(low));
  }

  return outBuffer[0] == 0xF7 && outBuffer[outLen - 1] == 0xEE;
}

bool enqueueRS485Command(const uint8_t *data, size_t len, CommandSource source)
{
  if (len == 0 || len > sizeof(rs485CommandQueue[0].buffer))
    return false;

  if (rs485CommandQueueCount >= RS485_COMMAND_QUEUE_SIZE)
  {
    rs485TxDiagnostics.dropped++;
    if (!rs485QueueDropReported && mqtt.connected())
    {
      mqtt.publish("home/wallpad/log/warning", "RS485 TX queue full: dropping command");
      rs485QueueDropReported = true;
    }
    return false;
  }

  PendingRS485Command &slot = rs485CommandQueue[rs485CommandQueueTail];
  memcpy(slot.buffer, data, len);
  slot.length = static_cast<uint8_t>(len);
  slot.source = source;
  slot.queuedTime = millis();

  rs485CommandQueueTail = (rs485CommandQueueTail + 1) % RS485_COMMAND_QUEUE_SIZE;
  rs485CommandQueueCount++;
  rs485TxDiagnostics.enqueued++;
  if (rs485CommandQueueCount > rs485TxDiagnostics.peakDepth)
  {
    rs485TxDiagnostics.peakDepth = rs485CommandQueueCount;
  }

  return true;
}

bool hasPendingRS485Command()
{
  return rs485CommandQueueCount > 0;
}

PendingRS485Command &peekPendingRS485Command()
{
  return rs485CommandQueue[rs485CommandQueueHead];
}

void popPendingRS485Command()
{
  if (rs485CommandQueueCount == 0)
    return;

  rs485CommandQueueHead = (rs485CommandQueueHead + 1) % RS485_COMMAND_QUEUE_SIZE;
  rs485CommandQueueCount--;
}

bool isRS485BusIdle()
{
  return rs485.available() == 0 && elapsedSince(lastRS485ActivityTime) >= RS485_BUS_IDLE_MS;
}

void broadcastRs485TxFrame(const PendingRS485Command &command)
{
  if (ws.count() == 0 || ESP.getFreeHeap() <= 12000)
    return;

  String message = "TX[";
  message += commandSourceToString(command.source);
  message += "]: ";
  message += RS485Parser::frameToHex(command.buffer, command.length);
  ws.textAll(message);
}

void processRS485Incoming()
{
  int bytesProcessed = 0;
  while (rs485.available() && bytesProcessed < 50)
  {
    uint8_t byte = rs485.read();
    lastRS485ActivityTime = millis();
    rs485BytesSinceLastFrame++;
    if (rs485BytesSinceLastFrame > MAX_BYTES_WITHOUT_FRAME)
    {
      parser.reset();
      rs485BytesSinceLastFrame = 0;
    }
    parser.addByte(byte);
    bytesProcessed++;

    if (bytesProcessed % 10 == 0)
    {
      yield();
    }

    if (parser.isFrameReady())
    {
      RS485Frame frame = parser.parseFrame();

      if (ws.count() > 0 && ESP.getFreeHeap() > 12000 && frame.rawLength > 0)
      {
        String rawHex = RS485Parser::frameToHex(frame.raw, frame.rawLength);
        if (frame.valid)
        {
          ws.textAll("RX: " + rawHex);
        }
        else
        {
          ws.textAll("RX: [INVALID] " + rawHex);
        }
      }

      if (frame.valid)
      {
        consecutiveInvalidFrames = 0;
        rs485BytesSinceLastFrame = 0;
        yield();

        bool stateChanged = deviceManager.processFrame(frame);

        if (stateChanged)
        {
          String jsonState = DeviceDecoder::autoDecodeToJson(frame);

          String topic = "home/wallpad/";
          switch (frame.deviceType)
          {
          case DEVICE_LIGHT:
            topic += "light/" + String(frame.deviceAddress - 0x10) + "/state";
            break;
          case DEVICE_FAN:
            topic += "fan/state";
            break;
          case DEVICE_DOORLOCK:
            // SubCommand 0x40: 현관문 상태 broadcast / 0x43: 도어락 제어 응답
            if (frame.subCommand == DOOR_SUB_FRONTDOOR)
              topic += "frontdoor/state";
            else
              topic += "doorlock/state";
            break;
          case DEVICE_CLIMATE:
            topic += "climate/" + String(frame.deviceAddress - 0x10) + "/state";
            break;
          default:
            topic += "unknown/state";
          }

          mqtt.publish(topic.c_str(), jsonState.c_str(), true);
          yield();

          if (ws.count() > 0 && ESP.getFreeHeap() > 12000)
          {
            ws.textAll("STATE: " + jsonState);
          }
        }
      }
      else
      {
        consecutiveInvalidFrames++;
        if (consecutiveInvalidFrames >= MAX_CONSECUTIVE_INVALID)
        {
          consecutiveInvalidFrames = 0;
          rs485BytesSinceLastFrame = 0;
          if (WiFi.status() == WL_CONNECTED && mqtt.connected())
          {
            mqtt.publish("home/wallpad/log/warning", "RS485: too many invalid frames");
          }
        }
      }
    }
  }
}

void processPendingRS485Command()
{
  if (!hasPendingRS485Command())
    return;

  if (elapsedSince(lastRS485TxTime) < RS485_TX_MIN_INTERVAL_MS)
    return;

  PendingRS485Command &command = peekPendingRS485Command();
  bool forcedTx = elapsedSince(command.queuedTime) >= RS485_TX_MAX_WAIT_MS;
  if (!forcedTx && !isRS485BusIdle())
  {
    rs485TxDiagnostics.blockedByBus++;
    return;
  }

  if (forcedTx)
  {
    rs485TxDiagnostics.forcedTx++;
  }

  rs485.write(command.buffer, command.length);
  lastRS485TxTime = millis();
  rs485TxDiagnostics.dequeued++;
  broadcastRs485TxFrame(command);
  popPendingRS485Command();

  if (rs485CommandQueueCount == 0)
  {
    rs485QueueDropReported = false;
  }
}

void markMonitorSessionActive()
{
  if (!ENABLE_MONITOR_PRIORITY)
    return;

  monitorSessionActive = true;
  lastMonitorActivityMs = millis();
}

void markMonitorSessionInactive()
{
  if (!ENABLE_MONITOR_PRIORITY)
    return;

  monitorSessionActive = false;
}
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
void loop()
{
  if (!isAPMode)
  {
    ArduinoOTA.handle();
  }

  if (otaInProgress)
  {
    delay(1);
    return;
  }

  // 재부팅 예약 처리 (HTTP 응답 완료 후 안전하게 재부팅)
  if (shouldReboot && millis() - rebootScheduledTime >= 2000)
  {
    // Serial.println("[SYSTEM] Rebooting now...");
    // Serial.flush(); // 시리얼 버퍼 비우기
    delay(100);
    ESP.restart();
  }

  // 메모리 경고 (임계값 이하일 때만)
  if (millis() - lastMemoryCheck > MEMORY_CHECK_INTERVAL)
  {
    lastMemoryCheck = millis();
    uint32_t freeHeap = ESP.getFreeHeap();
    if (freeHeap < MEMORY_WARNING_THRESHOLD)
    {
      // Serial.printf("[WARNING] Low memory: %u bytes\n", freeHeap);
      if (WiFi.status() == WL_CONNECTED && mqtt.connected())
      {
        char msg[64];
        snprintf(msg, sizeof(msg), "Low memory: %u bytes", freeHeap);
        mqtt.publish("home/wallpad/log/warning", msg);
      }
    }
  }

  // RS485 활동 감시 Watchdog 활성화 (부팅 5분 후 - 초기 연결 안정화 대기)
  if (!rs485ActivityWatchdogEnabled && millis() > RS485_WATCHDOG_ENABLE_DELAY_MS)
  {
    rs485ActivityWatchdogEnabled = true;
  }

  // RS485 10분 무수신 시 재부팅 (XY-017 래치 또는 파서 비정상 복구)
  if (rs485ActivityWatchdogEnabled && !isAPMode && !otaInProgress)
  {
    if (millis() - lastRS485ActivityTime > RS485_ACTIVITY_TIMEOUT_MS)
    {
      if (WiFi.status() == WL_CONNECTED && mqtt.connected())
      {
        mqtt.publish("home/wallpad/log/warning", "RS485 silence timeout: rebooting");
        delay(300);
      }
      ESP.restart();
    }
  }

  // Watchdog 플래그 처리
  if (shouldCheckWifiConnection)
  {
    shouldCheckWifiConnection = false;
    wifiReconnectAttempts++;

    // Serial.printf("[WATCHDOG] WiFi disconnected (attempt %d/%d)\n",
    //               wifiReconnectAttempts, MAX_WIFI_RECONNECT_ATTEMPTS);

    if (wifiReconnectAttempts >= MAX_WIFI_RECONNECT_ATTEMPTS)
    {
      // Serial.println("[WATCHDOG] Max reconnect attempts reached, restarting...");
      delay(100);
      ESP.restart();
    }
    else
    {
      // WiFi 재연결 시도
      WiFi.reconnect();
    }
  }
  else
  {
    // WiFi 연결되면 카운터 리셋
    if (WiFi.status() == WL_CONNECTED && wifiReconnectAttempts > 0)
    {
      // Serial.println("[WATCHDOG] WiFi reconnected successfully");
      wifiReconnectAttempts = 0;
    }
  }

  if (shouldCheckMqttConnection)
  {
    shouldCheckMqttConnection = false;

    // AP 모드에서는 MQTT 연결 시도 안 함
    if (!isAPMode)
    {
      if (!isMonitorSessionActive())
      {
        connectMQTT();
      }
    }
  }

  // WiFi 스캔 완료 확인
  checkWiFiScanComplete();

  static unsigned long lastBinarySensorCheck = 0;
  static unsigned long lastMqttReconnect = 0;
  static bool discoveryPublished = false;
  bool monitorActive = isMonitorSessionActive();

  // MQTT 연결 유지 (AP 모드가 아니고 WiFi 연결된 경우만)
  // 부팅 직후 20초 딜레이 추가 (웹 서버 완전 정상화 후)
  if (!isAPMode && WiFi.isConnected() && !mqtt.connected() && millis() > 20000)
  {
    if (!monitorActive && millis() - lastMqttReconnect > 5000)
    {
      lastMqttReconnect = millis();
      yield();
      // Serial.println("[MQTT] Attempting connection from loop()...");
      if (connectMQTT())
      {
        discoveryPublished = false; // 재연결 시 Discovery 다시 발행 준비
      }
    }
  }

  // Discovery 발행 (MQTT 연결 후, 백그라운드에서 천천히)
  // 여러 loop 사이클에 분산하여 blocking 최소화
  static int discoveryIndex = 0;
  static unsigned long lastDiscoveryTime = 0;

  if (!discoveryPublished && mqtt.connected())
  {
    if (monitorActive)
    {
      // 모니터링 접속 중에는 웹소켓 우선, discovery는 잠시 지연
    }
    else
    {
      // 200ms마다 1개씩 발행 (비동기 느낌)
      if (millis() - lastDiscoveryTime > 200)
      {
        lastDiscoveryTime = millis();

        if (publishDiscoveryEntity(discoveryIndex))
        {
          discoveryIndex++;
          if (discoveryIndex >= 13) // 총 13개 엔티티 (Light 3 + Fan 1 + Lock 1 + Climate 4 + Binary 3 + FrontDoor 1)
          {
            // Serial.println("[DISCOVERY] All entities published!");
            discoveryPublished = true;
            discoveryIndex = 0;
          }
        }
        else
        {
          // 발행 실패 시 다음번에 재시도
          // Serial.printf("[DISCOVERY] Entity %d publish failed, retry next loop\n", discoveryIndex);
        }
      }
    }
  }

  // 상태 조회 폴링 (3분마다, MQTT 연결 중에만)
  if (!isAPMode && mqtt.connected())
  {
    // 3분 경과 + 폴링 비활성 상태이면 폴링 시작
    if (statusPollIndex < 0 &&
        millis() - lastStatusPollTime >= STATUS_POLL_INTERVAL_MS)
    {
      statusPollIndex = 0;
      lastStatusPollEnqueue = 0;
    }

    // 순차 큐잉: 큐에 여유 있고 200ms 경과 시 1개씩 큐잉
    if (statusPollIndex >= 0)
    {
      if (getRS485CommandQueueDepth() < RS485_COMMAND_QUEUE_SIZE - 1 &&
          (lastStatusPollEnqueue == 0 ||
           millis() - lastStatusPollEnqueue >= STATUS_POLL_PACKET_INTERVAL_MS))
      {
        uint8_t pkt[11];
        memcpy_P(pkt, POLL_PACKETS[statusPollIndex], 11);
        enqueueRS485Command(pkt, 11, COMMAND_SOURCE_POLL);
        lastStatusPollEnqueue = millis();
        statusPollIndex++;
        if (statusPollIndex >= NUM_POLL_PACKETS)
        {
          statusPollIndex = -1;
          lastStatusPollTime = millis();
        }
      }
    }
  }

  processRS485Incoming();

  if (mqtt.connected())
  {
    mqtt.loop();
  }
  yield();

  processRS485Incoming();
  processPendingRS485Command();
  publishRs485TxDiagnostics();

  // Binary 센서 체크 (1초마다)
  static unsigned long lastWsPing = 0;
  if (millis() - lastBinarySensorCheck > 1000)
  {
    lastBinarySensorCheck = millis();
    if (mqtt.connected())
    {
      checkBinarySensors();
    }

    // WebSocket ping (30초마다)
    if (millis() - lastWsPing > 30000)
    {
      lastWsPing = millis();
      if (ws.count() > 0)
      {
        ws.pingAll();
        // Serial.printf("[WS] Ping sent to %u clients\n", ws.count());
      }
    }
  }

  // WebSocket 클린업 (죽은 연결 제거)
  ws.cleanupClients();
}

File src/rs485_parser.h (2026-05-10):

#ifndef RS485_PARSER_H
#define RS485_PARSER_H

#include <Arduino.h>
#include "checksum.h"

// 프레임 상수
#define FRAME_PREFIX 0xF7
#define FRAME_SUFFIX 0xEE
#define MIN_FRAME_SIZE 7 // Prefix + Length + Device + Cmd + Data(min 1) + Checksum + Suffix

// 장치 타입
enum DeviceType
{
  DEVICE_UNKNOWN = 0x00,
  DEVICE_LIGHT = 0x19,
  DEVICE_FAN = 0x2B,
  DEVICE_DOORLOCK = 0x1E,
  DEVICE_CLIMATE = 0x18
};

// 명령 타입
enum CommandType
{
  CMD_QUERY = 0x01,
  CMD_SET = 0x02,
  CMD_RESPONSE = 0x04
};

// 파싱된 프레임 구조체
struct RS485Frame
{
  uint8_t prefix;
  uint8_t length;
  uint8_t deviceType;
  uint8_t command;
  uint8_t subCommand; // buffer[5]: 동일 deviceType 내 sub-protocol 구분 (예: 0x40 broadcast vs 0x43 control ack)
  uint8_t deviceAddress;
  uint8_t data[16]; // 최대 16바이트 데이터
  uint8_t dataLength;
  uint8_t checksum;
  uint8_t suffix;
  uint8_t raw[32];
  uint8_t rawLength;
  bool lengthValid;
  bool checksumValid;
  bool valid;
};

// RS485 프레임 파서 클래스
class RS485Parser
{
public:
  RS485Parser() : bufferIndex(0), frameReady(false)
  {
    memset(buffer, 0, sizeof(buffer));
  }

  // 바이트 단위로 수신 데이터 추가
  void addByte(uint8_t byte)
  {
    // 버퍼가 가득 찬 경우 리셋
    if (bufferIndex >= MAX_BUFFER_SIZE)
    {
      reset();
    }

    // Prefix 감지 시 버퍼 리셋
    if (byte == FRAME_PREFIX && bufferIndex > 0)
    {
      // 기존 불완전한 프레임 버리고 새로 시작
      bufferIndex = 0;
    }

    buffer[bufferIndex++] = byte;

    // Suffix 감지 시 프레임 완성 여부 확인
    if (byte == FRAME_SUFFIX && bufferIndex >= MIN_FRAME_SIZE)
    {
      frameReady = true;
    }
  }

  // 완전한 프레임이 수신되었는지 확인
  bool isFrameReady()
  {
    return frameReady;
  }

  // 프레임 파싱 및 검증
  RS485Frame parseFrame()
  {
    RS485Frame frame;
    memset(&frame, 0, sizeof(frame));
    frame.valid = false;

    if (!frameReady || bufferIndex < MIN_FRAME_SIZE)
    {
      reset();
      return frame;
    }

    // 원본 프레임 보존 (디버깅/모니터링용)
    frame.rawLength = (bufferIndex > 32) ? 32 : bufferIndex;
    memcpy(frame.raw, buffer, frame.rawLength);

    // 기본 구조 검증
    if (buffer[0] != FRAME_PREFIX || buffer[bufferIndex - 1] != FRAME_SUFFIX)
    {
      reset();
      return frame;
    }

    // 필드 추출
    frame.prefix = buffer[0];
    frame.length = buffer[1];
    frame.deviceType = buffer[3];
    frame.command = buffer[4];
    frame.subCommand = (bufferIndex >= 6) ? buffer[5] : 0x00;

    // Length 검증
    // 프로토콜 문서 기준 length는 프레임 전체 길이(예: 0x0B=11, 0x0D=13)로 사용됨.
    // 기존 구현과의 호환을 위해 (전체 길이-2) 포맷도 허용한다.
    bool lengthMatchesTotal = (frame.length == bufferIndex);
    bool lengthMatchesLegacy = (frame.length == bufferIndex - 2);
    frame.lengthValid = (lengthMatchesTotal || lengthMatchesLegacy);
    if (!frame.lengthValid)
    {
      reset();
      return frame;
    }

    // 장치 주소 및 데이터 추출
    if (bufferIndex >= 7)
    {
      // 공통 포맷: [..][Cmd][Func][Addr][Data...][Checksum][Suffix]
      frame.deviceAddress = buffer[6];

      // 데이터 길이 계산: 전체 - (Prefix + Length + Fixed + Device + Cmd + Func + Addr + Checksum + Suffix)
      int dataLen = bufferIndex - 9;
      if (dataLen > 0 && dataLen <= 16)
      {
        frame.dataLength = dataLen;
        memcpy(frame.data, &buffer[7], dataLen);
      }
      else
      {
        frame.dataLength = 0;
      }
    }

    frame.checksum = buffer[bufferIndex - 2];
    frame.suffix = buffer[bufferIndex - 1];

    // Checksum 검증 (Prefix 제외, Checksum과 Suffix 제외)
    uint8_t calculatedChecksum = Checksum::xorSum(&buffer[1], bufferIndex - 3);
    // 레거시(초기값 0x00) 프레임과의 호환을 위해 Prefix xor 이전값도 허용
    uint8_t calculatedChecksumLegacy = (uint8_t)(FRAME_PREFIX ^ calculatedChecksum);

    frame.checksumValid =
        (calculatedChecksum == frame.checksum) ||
        (calculatedChecksumLegacy == frame.checksum);

    if (frame.checksumValid)
    {
      frame.valid = true;
    }

    reset();
    return frame;
  }

  // 버퍼 리셋
  void reset()
  {
    bufferIndex = 0;
    frameReady = false;
    memset(buffer, 0, sizeof(buffer));
  }

  // 프레임을 Hex 문자열로 변환 (디버깅용)
  static String frameToHex(const uint8_t *data, size_t len)
  {
    String result = "";
    for (size_t i = 0; i < len; i++)
    {
      if (data[i] < 0x10)
        result += "0";
      result += String(data[i], HEX);
      if (i < len - 1)
        result += " ";
    }
    result.toUpperCase();
    return result;
  }

  // 디바이스 타입을 문자열로 변환
  static String deviceTypeToString(uint8_t deviceType)
  {
    switch (deviceType)
    {
    case DEVICE_LIGHT:
      return "Light";
    case DEVICE_FAN:
      return "Fan";
    case DEVICE_DOORLOCK:
      return "DoorLock";
    case DEVICE_CLIMATE:
      return "Climate";
    default:
      return "Unknown";
    }
  }

  // 명령 타입을 문자열로 변환
  static String commandTypeToString(uint8_t command)
  {
    switch (command)
    {
    case CMD_QUERY:
      return "Query";
    case CMD_SET:
      return "Set";
    case CMD_RESPONSE:
      return "Response";
    default:
      return "Unknown";
    }
  }

private:
  static const int MAX_BUFFER_SIZE = 32;
  uint8_t buffer[MAX_BUFFER_SIZE];
  int bufferIndex;
  bool frameReady;
};

#endif

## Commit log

2026-02-18 perf: 성능/기능 개선
    주요 변경사항:
    - WebSocket: monitor.htm script를 body 끝으로 이동하여 HTML 파싱 blocking 제거
    - WiFi: Hidden SSID 스캔 제외로 스캔 시간 단축
    - MQTT: 연결을 20초 후로 지연, Discovery 비동기 분산 발행 (200ms 간격)
    - CSS: 인라인 CSS를 외부 파일로 이동 (26% 크기 절감)
    - Climate: Discovery 설정 보완 및 mode 소문자 변경 (HA 호환성)
    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
2026-02-18 Add circuit
    [everyESP485.fzz, everyESP485_wtAMS1117.fzz, wallpad_bridge_wtAMS1117.fzz]
2026-02-19 fix: 환경 설정 수정 및 보드 이름 변경
2026-02-19 feat: WiFi 및 MQTT 설정을 credentials.h에서 로드하도록 수정
    [main.cpp]
2026-02-21 fix: 회로도 수정
    [wallpad_bridge_wtAMS1117.fzz]
2026-03-21 feat: RS485 프레임 처리 및 모니터링 개선
2026-03-22 feat: OTA 펌웨어 업데이트 기능 추가 및 문서화
2026-03-22 feat: RS485 제어 및 모니터링 개선, 테스트 명령 및 문서 업데이트
2026-03-24 feat: RS485 송신 간격 제어 및 활동 감시 기능 추가
2026-03-27 feat: RS485 송신 대기열 및 진단 기능 추가
2026-03-27 feat: 상태 조회 폴링 기능 추가 및 관련 변수 초기화
2026-03-27 docs: 문서 갱신
2026-04-28 feat: PlatformIO 설정 및 코드 개선, 보드별 시리얼 방식 추가
2026-04-28 Refactor: RS485 모니터 UI 개선 및 기능 고도화
    - UI/UX 개편: 응답형 2단 레이아웃 도입 및 상단 네비게이션 바 추가
    - 콘솔 기능 강화: 알려진 코드 필터링, HEX 바이트 분석 및 숨김 기능 추가
    - 기능 업데이트: JS 로직 최적화(로컬 스토리지 지원), WiFi 설정 페이지 UI 동기화
    - 시스템 정보 확장: JSON 응답에 MQTT 연결 상태 및 업타임 정보 추가
    - 디자인 개선: 상태 표시기 및 진단 항목 스타일 현대화
2026-05-10 feat: 현관문 broadcast 채널 지원 + 디바이스 메타정보 분리
    - RS485Parser: subCommand(buffer[5]) 필드 추가 — 동일 deviceType 내
    sub-protocol을 구분하기 위한 채널 식별자
    - 도어락(0x1E) sub-protocol 분리: 0x40(현관문 상태 broadcast) /
    0x43(도어락 제어 응답)
    - HA 신규 엔티티: 현관문 binary_sensor (device_class: door,
    토픽 home/wallpad/frontdoor/state) Discovery 자동 등록
    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
